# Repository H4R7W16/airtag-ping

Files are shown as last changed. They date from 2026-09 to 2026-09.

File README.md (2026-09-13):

# PING · der kleine Schlüsselwächter

**Ein AirTag-Cover für den Schlüsselbund – in FreeCAD konstruiert, mit zwei PETG-Druckteilen, zwei gesicherten Schrauben und einem Zwinkern.**

Dieses öffentliche Repository dokumentiert den Entwurf und macht die Dateien, den Erzeugungscode und die Prüfmethoden zugänglich. **Stand: digital geprüfter Konstruktionsprototyp; noch nicht physisch gedruckt oder belastungsgeprüft.**

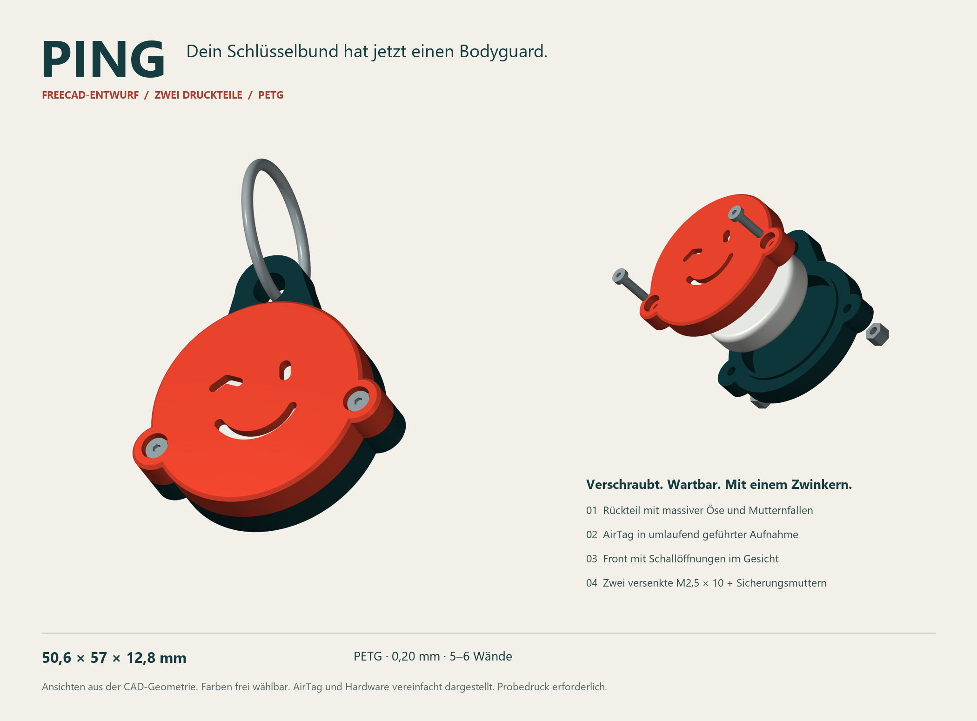
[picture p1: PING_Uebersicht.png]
PING – tatsächliche CAD-Geometrie, montiert und explodiert


## Direkt zu den Dateien

| Zweck | Datei |
|---|---|
| In FreeCAD bearbeiten | [PING_AirTag.FCStd](PING_AirTag.FCStd) |
| Rückteil drucken | [PING_Rueckteil.stl](PING_Rueckteil.stl) |
| Front drucken | [PING_Front.stl](PING_Front.stl) |
| In anderer CAD-Software öffnen | [PING_Montage.step](PING_Montage.step) |
| Druck, Teileliste und Montage | [Bebilderte Anleitung](README_Druck_und_Montage.md) |
| Erzeugung nachvollziehen | [FreeCAD-Makro](PING_erzeugen.FCMacro) · [Reproduktion](docs/REPRODUZIEREN.md) |
| Ergebnis überprüfen | [Prüfprogramm](verify_model.py) · [Prüfbericht](Pruefbericht.json) · [Prüfmethoden](docs/PRUEFUNG.md) |
| Herkunft und Entscheidungen | [Entwurfsdokumentation](docs/ENTWURF_UND_HERKUNFT.md) |

Einzeldateien über **Download raw file** herunterladen oder das gesamte Repository mit **Code → Download ZIP** beziehen. STL- und CAD-Dateien sind echte binäre Dateien, keine Git-LFS-Platzhalter.

## Konstruktion

- **50,6 × 57 × 12,8 mm** ohne Schlüsselring; Aufnahme Ø32,5 × 8,6 mm für den dokumentierten AirTag-Hüllraum Ø31,9 × 8,0 mm.
- Integrierte Öse im Rückteil: 6,4 mm dick, Ringöffnung Ø6,5 mm.
- Umlaufende Zentrierlippe; Front mit Gesicht als Schallöffnung.
- Zwei **M2,5×10-Linsenkopfschrauben** und zwei **selbstsichernde M2,5-Muttern, SW5 × 3,8 mm**. Genaue Anforderungen stehen in der [Stückliste](README_Druck_und_Montage.md#einkaufsliste).
- Für einen FDM-Drucker mit 0,4-mm-Düse und PETG ausgelegt. Startwerte: 0,20-mm-Schichten, 5–6 Wände, 40–50 % Infill. Beide STLs liegen bereits in Drucklage. Ein konkretes Drucker-/Filamentprofil wurde noch nicht erprobt.

Das Modell enthält native FreeCAD-Bodies, Skizzen, Pads, Pockets und Fasen. Die Tabelle steuert Funktionsmaße; Außenkontur, Gesicht, Schraubenpositionen und Muttern-Sechskante sind fixierte, bearbeitbare Skizzen. Es ist **kein vollständig skalierbares Universalgehäuse**.

## Was ist überprüft?

Die lokale FreeCAD-Prüfung öffnet das gespeicherte Modell erneut und kontrolliert Körpergültigkeit, Außenmaße, Kollisionen mit AirTag und Hardware sowie STEP- und STL-Exporte. Die Prüfprogramme, Toleranzen und Ergebnisse stehen offen im Repository.

Der GitHub-Workflow prüft **SHA-256-Dateiintegrität und Python-Syntax**, nicht die CAD-Geometrie. Für Letztere ist eine lokale FreeCAD-Laufzeit erforderlich. Prüfsummen sichern die Konsistenz dieses Dateistands; sie sind kein unabhängiger Sicherheitsnachweis.

**Noch offen:** Passung mit realem AirTag, Klappern, Drucktoleranzen, Signalton/Funkfunktion, Schraubensicherung sowie Zug-, Verdreh- und Falltests. Es gibt keine zugesicherte Bruchlast, keine FEM und keine Einstufung als unzerbrechlich. Hinweise dazu und eine ausfüllbare [Testvorlage](docs/PROBEDRUCK_PROTOKOLL.md) helfen bei der weiteren Erprobung.

## Kurz überprüfen

Ohne FreeCAD, mit Python 3:

```console
python verify_files.py
```

Mit der zu FreeCAD gehörenden Python-Laufzeit unter Windows, aus dem Repository-Ordner:

```powershell
& 'C:\Program Files\FreeCAD 1.1\bin\python.exe' .\verify_model.py
```

Ergebnis: `build/Pruefbericht.json`. Details, vollständige Neu-Erzeugung und bekannte Plattformgrenzen: [Reproduzieren](docs/REPRODUZIEREN.md).

## Quellen, Beiträge und Nutzungsrechte

Der Entwurf wurde im Dialog mit OpenAI Codex erstellt und mit FreeCAD 1.1.3 umgesetzt. Die Ansichten stammen aus CAD-Geometrie; AirTag und Metallteile sind vereinfacht dargestellt. Maße und Materialquellen sind in der [Anleitung](README_Druck_und_Montage.md#quellen-und-eigene-festlegungen) verlinkt. Keine Verbindung zu oder Freigabe durch Apple.

Beobachtungen können als Issue mit Drucker, Material, Profil, Commit und Fotos dokumentiert werden. Bitte geometrische Prüfung und reale Erprobung getrennt ausweisen.

Für dieses öffentliche Dokumentationsrepository wurde bislang **keine gesonderte freie Nachnutzungslizenz festgelegt**. Eine solche Lizenz wird nicht allein aus der öffentlichen Sichtbarkeit abgeleitet.

*English: PING is a FreeCAD AirTag keychain enclosure. CAD, printable STLs, STEP, generator, validation scripts and documentation are provided for inspection. Digitally checked prototype; physical testing is still pending.*

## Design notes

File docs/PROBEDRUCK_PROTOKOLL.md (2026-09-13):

# Probedruck-Protokoll

**Leere Vorlage, kein bestandener Testbericht.** Für einen tatsächlichen Test kopieren und ausfüllen.

| Feld | Eintrag |
|---|---|
| Datum / prüfende Person | |
| Repository-Commit / Dateiprüfsummen | |
| Änderungen am Entwurf | |
| Drucker / Düse / Slicer und Version | |
| Materialhersteller / Sorte / Charge / Trocknung | |
| Schichthöhe / Wände / Infill / Boden und Deckschichten | |
| Temperaturen / Kühlung / Druckausrichtung | |
| Tatsächliche Schrauben und Muttern | |
| AirTag-Generation | |

## Sicht- und Passprüfung

- [ ] Keine Risse, fehlenden Wände oder sichtbare schlechte Schichtbindung.
- [ ] Muttern sitzen vollständig; Schrauben greifen durch den Sicherungsbereich.
- [ ] Fuge schließt umlaufend ohne Verformung.
- [ ] AirTag lässt sich einlegen und wieder entnehmen; kein störendes Klappern.
- [ ] Ring lässt sich aufziehen und frei bewegen.
- [ ] Signalton, Erkennung und verfügbare Suchfunktionen geprüft.

Beobachtungen, Messwerte und Fotos:

## Mechanische Erprobung mit Dummy

Prüfaufbau, Belastungsrichtung, gemessene Kraft, Anzahl der Lastwechsel bzw. Fallhöhe und Untergrund dokumentieren. Keine pauschale Freigabe aus einem einzelnen erfolgreichen Test ableiten.

Aufbau und Belastung:

Beobachtungen, Schäden und Fotos:

## Schlussfolgerung

Was wurde tatsächlich beobachtet? Was bleibt ungetestet? Welche Änderung wird daraus abgeleitet?

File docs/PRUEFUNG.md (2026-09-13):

# Prüfmethode und Aussagegrenzen

`verify_model.py` wird mit einer FreeCAD-Python-Laufzeit ausgeführt und öffnet die FCStd-Datei erneut. Es prüft den dokumentierten **Ausgangsentwurf**, kein beliebig geändertes parametrisches Modell. Die Prüfmaße sind bewusst unabhängig vom Generator als Sollwerte hinterlegt.

| Prüfung | Kriterium |
|---|---|
| CAD-Körper | Zwei Bodies; je genau ein gültiger Solid, Volumen > 1000 mm³ |
| Vollständige Rückteilkontur | Breite 50,6 und Höhe 57,0 mm, Toleranz 0,01 mm |
| Hälften | Überschneidungsvolumen < 0,00001 mm³ |
| AirTag-Passraum | Vollständiger Hüllzylinder Ø31,9 × 8,0 mm, von Z=2,4 bis 10,4, kollisionsfrei |
| Schrauben | Zwei vereinfachte Ø2,5×10-Schäfte, Kopf Ø4,5×1,5 mm, kollisionsfrei |
| Muttern | Sechskant SW5×3,8 mm, Z=1 bis 4,8, kollisionsfrei |
| Gewindeeingriff | Nominale axiale Maßkette: 0,6 mm Überstand durch Mutter, Schraubenspitze 0,4 mm innerhalb der Rückseite |
| Beispielring | Geschlossener Torus, Außen-Ø29,2 mm, Draht-Ø2,2 mm, kollisionsfrei |
| STEP | Zwei gültige Solids; beidseitige CAD/STEP-Volumendifferenz jeweils < 0,0001 mm³ |
| STL | Geschlossenes Netz, eine Komponente, Zmin innerhalb 0,0001 mm auf dem Druckbett |
| Exporttreue STL/CAD | Symmetrische Volumendifferenz < 0,3 % und alle sechs Bounding-Box-Grenzen innerhalb 0,05 mm |
| Neuberechnung | Kein Objektstatus mit `Invalid` oder `Error` |

Die STL-Geometrie wird als Volumenkörper rekonstruiert und mit der CAD-Geometrie in Drucklage verglichen. Ein nur geschlossener, aber geometrisch falscher Export reicht damit nicht aus. Die 0,3 % berücksichtigen die Tessellierung; sie sind **keine Fertigungstoleranz**.

Hardware wird vereinfacht geprüft: keine Gewindegeometrie, keine Nylon-Verformung, kein Einschraubmoment und kein detaillierter Splitring-Montagevorgang. Der nominelle Schraubenüberstand ist eine Maßkettenprüfung, kein Test der tatsächlichen Sicherungswirkung. Ein geteilter Ring kann beim Aufziehen mehr Platz benötigen als der modellierte geschlossene Torus.

## Öffentliche Nachweise

- `Pruefbericht.json`: Test auf den veröffentlichten Produktdateien.
- `Reproduktionsbericht.json`: Test auf separaten, frisch aus dem veröffentlichten Makro erzeugten Produktdateien.
- `SHA256SUMS`: Integritätsmanifest der versionierten Projektdateien.
- GitHub-Workflow: prüft das Manifest sowie die Syntax der Python-Programme/des Makros. Er installiert kein FreeCAD und behauptet keine automatische CAD-Prüfung.

Die Berichte stammen aus der Erstellung dieses Projekts. Sie sind nachvollziehbar und erneut ausführbar, aber keine externe Zertifizierung oder unabhängige Laborprüfung.

## Offene physische Validierung

Kein realer Druck, keine Fall-/Zug-/Dauerbelastung, keine FEM, kein Test der Temperaturbeständigkeit, keine Messung des Signaltons oder der Funkfunktion. Materialdaten eines PETG-Filaments übertragen sich nicht automatisch auf den gedruckten Bauteilquerschnitt.

Die [Probedruck-Vorlage](PROBEDRUCK_PROTOKOLL.md) trennt Beobachtungen von Schlussfolgerungen. Änderungen an Material, Druckausrichtung, Schichtbindung, Passung oder Verschraubung erfordern eine erneute praktische Bewertung.

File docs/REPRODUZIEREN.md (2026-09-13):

# Dateien und Geometrie reproduzieren

## Referenzumgebung

Getestet unter Windows mit FreeCAD **1.1.3**, Build `145529fe741292ff0b3977a01195bf0247425794`, dessen eingebauter Python-3.11-Laufzeit und OpenCASCADE. Für die optionalen CAD-Renderings wurden VTK 9.3.1 und Pillow 12.0.0 verwendet. Es werden keine externen FreeCAD-Add-ons benötigt.

FreeCAD enthält C++-Python-Module. Ein beliebiges `pip install` oder der normale System-Python ersetzt diese Laufzeit nicht. Die Dokumentation beschreibt die tatsächlich getestete Windows-Konfiguration. Andere FreeCAD-Versionen und Betriebssysteme wurden nicht ausgeführt. Die Skripte unterstützen optional `FREECAD_LIB` als Modul-Suchpfad; passende Binärversionen und abhängige Bibliotheken bleiben Voraussetzung.

## 1. Dateistand prüfen

Im entpackten Repository mit Python 3:

```console
python verify_files.py
```

Das Skript prüft alle in `SHA256SUMS` gelisteten Dateien. Ein abweichender Hash beendet die Prüfung mit Fehler. Dafür ist kein FreeCAD nötig. Bei beabsichtigten Änderungen lässt sich das Manifest mit `python verify_files.py --write` neu erstellen; anschließend dokumentieren, was geändert und neu geprüft wurde.

## 2. Mitgelieferte Geometrie prüfen

PowerShell im Repository-Ordner:

```powershell
$pingPython = 'C:\Program Files\FreeCAD 1.1\bin\python.exe'
& $pingPython .\verify_model.py
```

Die Prüfung liest die versionierte FCStd-, STEP- und STL-Dateien. Sie verändert das CAD nicht. Standardmäßig schreibt sie ihren Bericht nach `build/Pruefbericht.json`. Ohne `-O` ausführen, damit Assertions aktiv bleiben. Das Skript verweigert einen optimierten Python-Lauf.

```powershell
& $pingPython .\verify_model.py --artifact-dir . --report .\build\mein-pruefbericht.json
```

## 3. Konstruktion neu erzeugen

```powershell
& $pingPython .\PING_erzeugen.FCMacro
& $pingPython .\verify_model.py --artifact-dir .\build --report .\build\neu-erzeugt-pruefung.json
```

Der Generator legt standardmäßig `build/` an und erstellt dort FCStd, STEP, STL sowie BREP-Zwischenexporte. Die versionierten Originaldateien bleiben dadurch erhalten. Wiederholungen überschreiben gleichnamige Dateien innerhalb von `build/`. Der Generator baut seine dokumentierten Ausgangswerte; Änderungen an einer FCStd-Datei werden nicht als Eingabe übernommen.

Ein anderer Zielordner kann pro Sitzung gewählt werden:

```powershell
$env:PING_OUTPUT_DIR = Join-Path (Get-Location) 'build-variante'
& $pingPython .\PING_erzeugen.FCMacro
Remove-Item Env:PING_OUTPUT_DIR
```

Alternativ das Erzeugermakro in FreeCAD über **Makro → Makros** auswählen und ausführen. Auch dort ist `build/` neben dem Makro der Standard-Ausgabeordner. Bei der Kommandozeilenausführung wird die FreeCAD-GUI für Ansichtsattribute im Offscreen-Modus initialisiert. Die Referenzumgebung meldete dabei Qt-/OpenGL-Warnungen; die maßgebliche Erfolgskontrolle sind die exportierten Dateien und die anschließende Geometrieprüfung.

## 4. Ergebnisse vergleichen

FCStd/STEP können Zeitstempel, Ansichtsmetadaten oder Serialisierungsdetails enthalten. Deshalb ist ein identischer SHA-256-Hash eines **neu erzeugten** CAD-Containers nicht garantiert. Die Prüfsummen gelten für den veröffentlichten Stand. Für die Reproduktion vergleichen wir Geometrie, Volumina, Außenmaße und gültige Exporte innerhalb der [dokumentierten Toleranzen](PRUEFUNG.md).

`Pruefbericht.json` enthält die Prüfung des veröffentlichten Dateistands. `Reproduktionsbericht.json` enthält denselben Test auf einem separaten frisch erzeugten Satz. Kleine Gleitkommaabweichungen sind möglich. Das allein beweist keine echte mechanische Robustheit.

## 5. Optionale Vorschau erzeugen

Die Referenzinstallation enthielt VTK und Pillow. Mit diesen Bibliotheken in derselben FreeCAD-Python-Laufzeit:

```powershell
& $pingPython .\render_preview.py
```

Die Bilder entstehen unter `build/previews/`. Für einen neu erzeugten Datensatz:

```powershell
& $pingPython .\render_preview.py --artifact-dir .\build --output-dir .\build\neue-ansichten
```

Schriften: standardmäßig Windows Segoe UI, alternativ DejaVu Sans; eigene TTF-Pfade über `PING_FONT_REGULAR` und `PING_FONT_BOLD`. Grafiktreiber, VTK und Schrift beeinflussen die Bildausgabe. Renderings werden nicht als pixelidentisch reproduzierbar behauptet. Die mitgelieferte `PING_FreeCAD_Ansicht.png` ist eine separat aus der echten FreeCAD-GUI gespeicherte Modellansicht; das VTK-Skript erzeugt die vier übrigen Bilder.

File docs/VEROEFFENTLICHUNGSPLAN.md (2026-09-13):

# Veröffentlichung von PING

Auftrag: Das AirTag-Cover öffentlich auf GitHub dokumentieren und die Ergebnisse für Dritte überprüfbar machen.

1. Projektdateien gezielt übernehmen: CAD, STEP, STL, Ansichten, Generator, Prüf- und Renderprogramm. Keine lokalen App-Logs, Backups oder privaten Workspace-Notizen veröffentlichen.
2. README, Reproduktionsanleitung, Prüfmethoden und Herkunft dokumentieren. Physische Erprobung ausdrücklich als offen kennzeichnen.
3. Generator in ein separates Ausgabeverzeichnis schreiben lassen. Lokale Prüfprogramme auf mitgelieferte und neu generierte Artefakte anwenden. Geometrie von CAD, STEP und STL vergleichen.
4. SHA-256-Manifest und schlanken GitHub-Integritätscheck bereitstellen. Dieser ersetzt keine FreeCAD-Geometrieprüfung.
5. Neues öffentliches Repository H4R7W16/airtag-ping anlegen, sauberen Checkout unter Repos verwenden, Dateien committen und pushen. Vor Commit/Push Remote abrufen und per Fast-forward synchronisieren.
6. Öffentliche Sichtbarkeit, Dateistand und automatischen Check prüfen. Commit und URL im lokalen Projekt-Handoff dokumentieren.

Die Veröffentlichung ist durch den Nutzerauftrag freigegeben. Keine Änderungen am Produktdesign vorgesehen; Anpassungen betreffen Reproduzierbarkeit und Dokumentation.

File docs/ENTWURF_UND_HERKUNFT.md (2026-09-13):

# Entwurf, Herkunft und Entscheidungen

## Auftrag

Ein schönes, stabiles AirTag-Cover für den Schlüsselbund, druckbar auf einem 3D-Drucker, gerne überraschend oder mit Witz. Schrauben waren erlaubt. Die Konstruktion sollte in FreeCAD entstehen. Anschließend wurde eine öffentliche Dokumentation für die Überprüfung durch Dritte beauftragt.

## Ergebnis

„PING“ ist eine verschraubte Grinse-Kapsel. Die Öse gehört zum Rückteil; eine umlaufende Lippe führt die Front. Zwei seitliche Verschraubungen liegen außerhalb des AirTag-Raums. Augen und Mund sind zugleich Schallöffnungen. Die zweiteilige Bauweise erlaubt zwei Farben ohne Mehrmaterialdruck.

Eine alleinige Schnappverbindung wurde wegen ihrer Abhängigkeit von Material und Drucktoleranz nicht gewählt. Ein umlaufendes gedrucktes Gewinde hätte mehr Bedienraum benötigt. Die verschraubte Lösung ist wartbar, dafür größer und beim Batteriewechsel werkzeugabhängig.

## Herkunft und Werkzeuge

Entwurf am 13.09.2026 im Dialog mit OpenAI Codex. Das native CAD wurde mit FreeCAD 1.1.3 über dessen Python-API konstruiert. Es handelt sich um native Skizzen-/PartDesign-Operationen, keine bloß importierte STL. Die Produktansichten wurden mit VTK/Pillow aus den realen CAD-Körpern gerendert; eine weitere Ansicht direkt in der FreeCAD-GUI.

Die Face-/AirTag-Darstellungen sind keine Hersteller-CAD-Daten. Für den AirTag wurde der von Apple veröffentlichte Hüllzylinder angenommen. PETG und die 0,4-mm-Düse sind Entwurfsannahmen; ein konkreter Drucker wurde nicht festgelegt. Quellen stehen in der Druck-/Montageanleitung.

## Während der Entwicklung behobener Fehler

Die zweidimensionale Vereinigung koplanarer FreeCAD-Flächen hinterließ zunächst mehrere Teilflächen. Die Übernahme allein der ersten Teilfläche in eine Skizze ließ Teile der Öse bzw. Schraubenohren fehlen. Der Fehler wurde durch einen Vergleich mit den erwarteten Außenmaßen erkannt. Das veröffentlichte Makro vereinigt stattdessen kurz extrudierte Körper und übernimmt ihre vollständige Bodenfläche. Zusätzliche Außenmaßprüfungen schützen vor demselben Fehler.

Die Dokumentation erwähnt diesen Befund, damit nachvollziehbar bleibt, warum eine allgemeine „Shape valid“-Prüfung allein nicht ausgereicht hätte. Die veröffentlichten Produktdateien enthalten die korrigierte Kontur.

## Änderungen für die Veröffentlichung

Keine Änderung der Produktgeometrie. Generator-Ausgaben wurden nach `build/` verlegt; Prüf-/Renderprogramme erhielten Eingabe- und Ausgabeoptionen. Lokale Installationspfade wurden durch die dokumentierte FreeCAD-Laufzeit bzw. `FREECAD_LIB` ersetzt. Zusätzlich wurden Exportvergleiche und Dateiintegrität aufgenommen. Interne App-Logs, Backups und private Workspace-Notizen gehören nicht zu diesem Repository.

## Änderungsdisziplin

Bei Varianten Generator und Sollprüfungen bewusst anpassen, neu erzeugen und prüfen. Alte Berichte nicht als Beleg für eine neue Geometrie übernehmen. Gedruckte Testteile möglichst mit Commit-ID, Material und Slicerprofil dokumentieren.

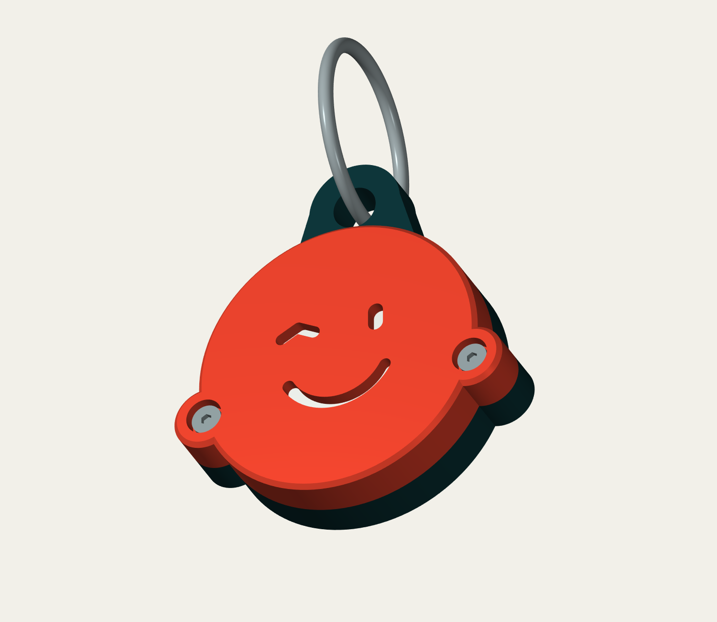
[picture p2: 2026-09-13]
PING_Vorschau.png

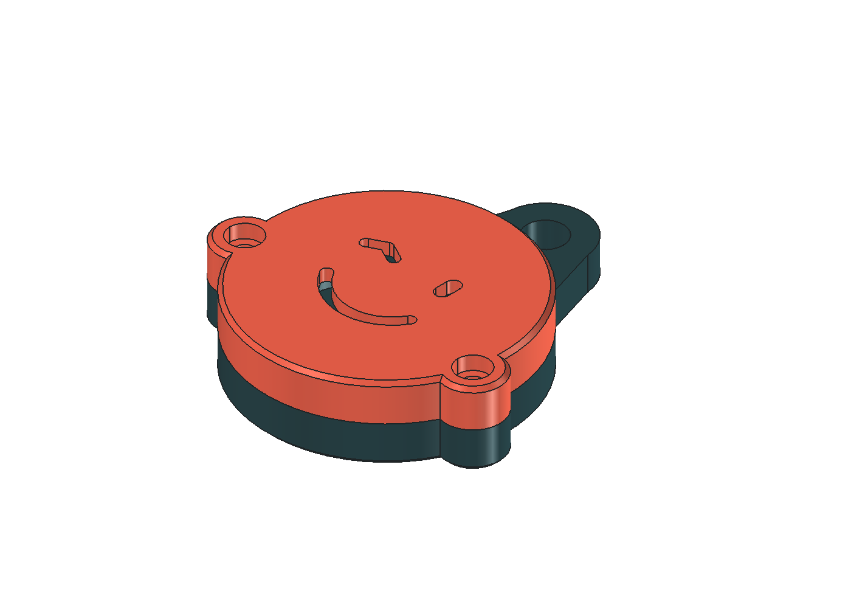
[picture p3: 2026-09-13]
PING_FreeCAD_Ansicht.png

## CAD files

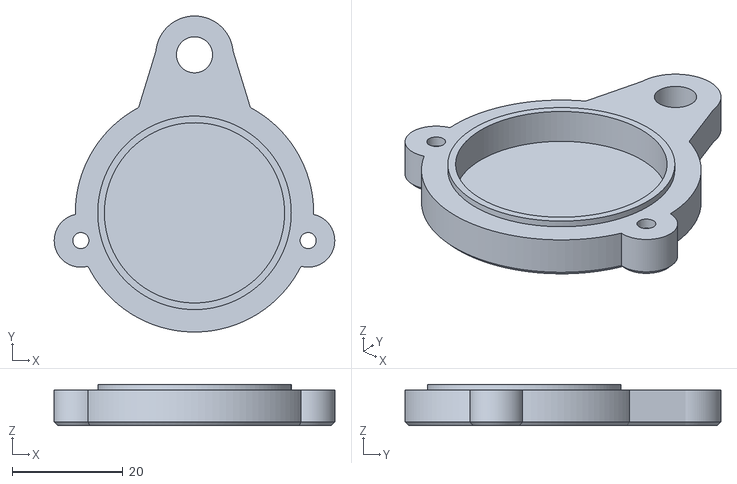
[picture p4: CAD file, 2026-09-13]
PING_Rueckteil.stl
50.6 x 57.0 x 7.40

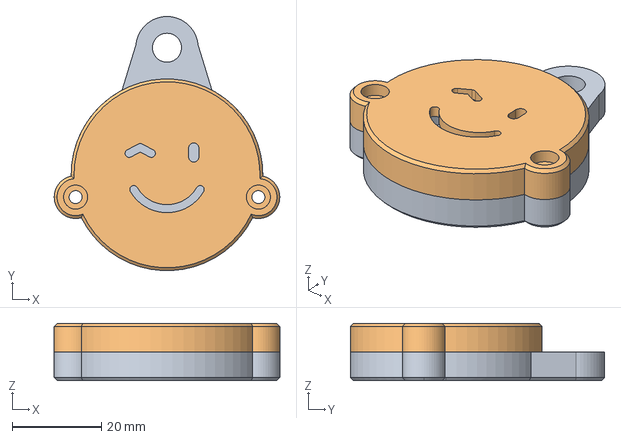
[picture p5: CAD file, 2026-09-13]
PING_AirTag.FCStd
50.6 x 57.0 x 12.8 mm
02 · Rückteil / PETG dunkel
03 · Front / PETG koralle

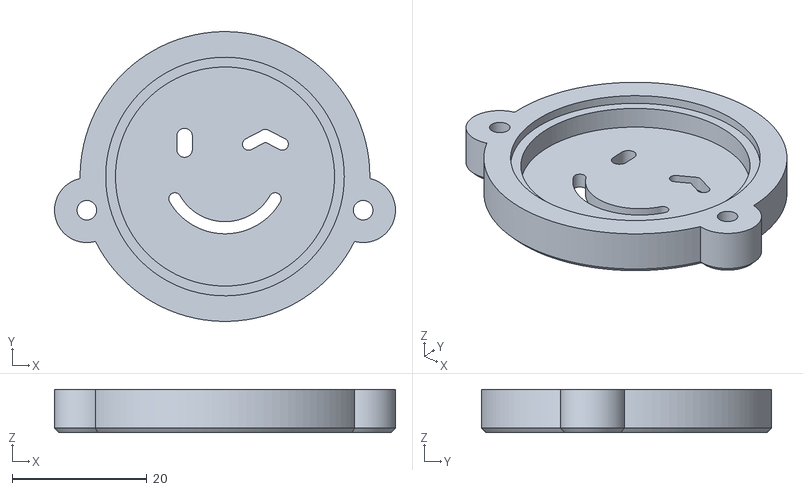
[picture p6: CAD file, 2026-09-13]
PING_Front.stl
50.6 x 43.0 x 6.40

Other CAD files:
PING_Montage.step

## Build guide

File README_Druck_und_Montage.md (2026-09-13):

# PING – der kleine Schlüsselwächter

Ein zwinkerndes AirTag-Cover mit massiver Öse, zwei versenkten Schrauben und wartbarem Gehäuse. Entworfen und geprüft mit FreeCAD 1.1.3, 13.09.2026. **Konstruktionsstand: druckbarer Prototyp, noch kein physisch erprobtes Produkt.**

PING – CAD-Ansichten

## Dateien

| Datei | Verwendung |
|---|---|
| `PING_AirTag.FCStd` | Native FreeCAD-Datei mit zwei Bodies, Skizzen, Pads, Pockets, Fasen und Parametertabelle. Hälften in Montageposition. |
| `PING_Rueckteil.stl` | Einmal drucken, bereits in Drucklage. |
| `PING_Front.stl` | Einmal drucken, bereits in Drucklage. |
| `PING_Montage.step` | Zwei getrennte Körper zum Austausch mit anderer CAD-Software; Montageposition. |
| `PING_erzeugen.FCMacro` | Reproduzierbarer Erzeuger für FreeCAD; schreibt standardmäßig in `build/`. Ein vorhandener gleichnamiger Stand in diesem Ausgabeordner wird überschrieben. |
| `Pruefbericht.json` | Ergebnisse der digitalen Geometrieprüfung. |

## Maße und Aufbau

| Merkmal | CAD-Nennmaß |
|---|---:|
| Komplettes Cover ohne Schlüsselring | 50,6 × 57,0 × 12,8 mm |
| Hauptscheibe | Ø43,0 mm |
| AirTag-Aufnahme | Ø32,5 × 8,6 mm |
| Zugrunde gelegter AirTag | Ø31,9 × 8,0 mm |
| Spiel für AirTag | 0,3 mm radial, insgesamt 0,6 mm in der Höhe |
| Frontwand und Boden | je 2,1 mm |
| Öse | 6,4 mm dick, Außenradius 7,0 mm |
| Schlüsselringöffnung | Ø6,5 mm; nominell 3,75 mm Material bis Außenrand oben |
| Umlaufende Führung | 1,0 mm hoch, 1,2 mm breit |
| Führungsspiel | 0,25 mm radial und axial |
| Schraubendurchgänge | Ø2,9 mm |
| Kopftaschen | Ø5,4 × 2,4 mm tief |
| Mutternfallen | SW5,35 × 4,8 mm tief |

Die Schlüsselringlast geht direkt in das Rückteil. Die Front verschließt den AirTag mit zwei Schrauben. Die umlaufende Lippe führt die Hälften und unterstützt sie gegen seitliche Verschiebung. Augen und Mund sind durchgehende Schallöffnungen. Die Front deckt den AirTag weitgehend ab, bietet durch diese Öffnungen aber keinen vollständigen Kratz- oder zusätzlichen Wasserschutz.

## Material und Druck

**Voreinstellung: FDM, PETG, Düse 0,4 mm.** Drucker und Material wurden nicht näher genannt. Petrol/Anthrazit hinten und Koralle/Orange vorne funktionieren ohne Mehrfarbdruck: jedes Teil erhält eine Filamentfarbe.

- Beide STL-Dateien in **Millimetern und mit 100 % Skalierung** importieren. Sie liegen mit der flachen Außenseite auf Z=0; die offenen Innenseiten zeigen nach oben.
- Schichthöhe 0,20 mm; 5–6 Wandlinien; mindestens 6 Boden-/Deckschichten; 40–50 % Gyroid als Startwert. Öse und Schraubenohren im Slicer bei Bedarf mit einem 100-%-Infill-Modifikator versehen. Mit dieser Wandzahl werden die schmalen Bereiche ohnehin weitgehend massiv.
- Normalerweise ohne Stützmaterial druckbar. In der Schichtvorschau besonders die kurzen Brücken über Kopf- und Mutternfallen prüfen. Falls das PETG-Profil dort unsauber brückt, lokal Stützen setzen oder das Brückenprofil anpassen.
- Materialtemperaturen und Kühlung nach dem bewährten Profil für das konkrete Filament wählen. Trockene PETG-Rolle verwenden. Kein ungeprüfter Universal-Temperaturwert.
- Die Außenfase reduziert scharfe Druckbettkanten. Einen verbliebenen Elefantenfuß an Bohrungen und Passflächen vorsichtig entgraten. Die funktionale Zentrierlippe nicht abschleifen, solange sie bereits leichtgängig passt.
- PLA eignet sich für einen ersten Formtest. Für die vorgesehene Nutzung ist zähes PETG die Ausgangsempfehlung. [Prusa: PETG](https://help.prusa3d.com/article/petg_2059)

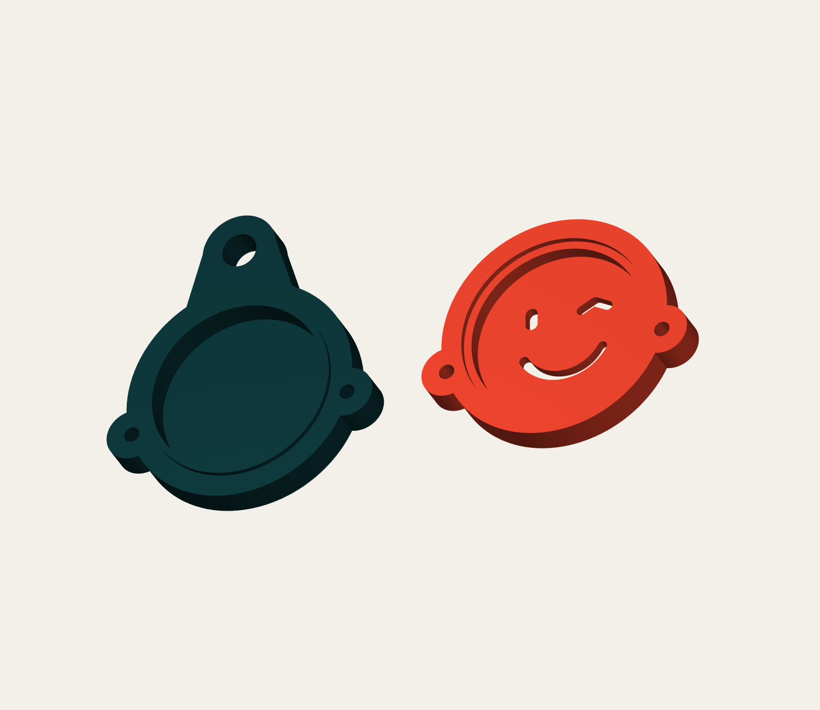
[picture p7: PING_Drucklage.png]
Beide Teile in Drucklage, von der offenen Innenseite gesehen


## Einkaufsliste

| Anzahl | Teil | Maßanforderung |
|---:|---|---|
| 2 | M2,5 × 10 mm Linsenkopf-Innensechskantschraube, z. B. ISO 7380-1 | Länge **unter dem Kopf** 10 mm, Kopf Ø maximal 4,5 mm, Kopfhöhe maximal 1,5 mm; Vollgewinde. Keine Senkkopfschraube. |
| 2 | Selbstsichernde M2,5-Sechskantmutter mit Nylonring | SW5,0 mm, Gesamthöhe 3,8 mm. Tatsächliches Lieferteil nachmessen; abweichende Bauformen sind möglich. |
| 1 | Geschlossener geteilter Schlüsselring aus Stahl | Etwa 28–30 mm außen, Draht etwa 2,0–2,2 mm. Virtuell geprüft: Ø29,2 mm außen / Draht Ø2,2 mm, als vereinfachter geschlossener Ring. |
| optional | Sehr dünne weiche Schaum-/Filzauflage | Nur falls der reale AirTag klappert; zunächst 0,3 mm dick und etwa Ø8–10 mm, zentral auf dem hinteren Boden. |

Keine Gewindeeinsätze, kein Klebstoff und keine gedruckten Gewinde nötig. Die selbstsichernden Muttern erschweren ein selbstständiges Losdrehen. Die Rückhaltung ist trotzdem regelmäßig am realen Schlüsselbund zu kontrollieren.

## Montage

1. Beide Teile entgraten. Zuerst ohne AirTag trocken zusammenstecken: Die Lippe muss in die Front gleiten und die umlaufende Trennfuge muss vollständig schließen.
2. Die beiden Muttern von der **Außenseite des Rückteils** in die Sechskanttaschen drücken. Metallische Auflagefläche tief in die Tasche, Nylonring nach außen. Die Muttern liegen anschließend ungefähr 1 mm unter der Rückseite. Beim ersten Einschrauben mit einem passenden Werkzeug gegenhalten, wenn sie noch lose sitzen.
3. Den AirTag ins Rückteil legen. Die verwendete digitale Prüfung basiert bewusst auf dem vollständigen Ø31,9 × 8,0-mm-Hüllzylinder; die genaue gewölbte Herstellerkontur wurde nicht nachmodelliert. Bei fühlbarem Spiel eine dünne zentrale weiche Auflage ergänzen. Nicht so viel unterlegen, dass die Fuge beim Schließen offen bleibt.
4. Die Front aufsetzen. Zwei M2,5×10-Schrauben von vorne einsetzen und abwechselnd vorsichtig von Hand anziehen. Die Flächen sollen satt anliegen, ohne sichtbare Verformung. Die Sicherungsmutter erzeugt schon vor dem Anschlag Widerstand; deshalb nicht allein nach dem Drehgefühl beurteilen.
5. Prüfen: Schraubenenden bleiben nominal 0,4 mm innerhalb des Rückteils und reichen 0,6 mm durch die vollständig eingesetzte 3,8-mm-Mutter. Beide Schrauben müssen durch den Nylonbereich greifen. Bei abweichender Mutterhöhe die Länge neu prüfen.
6. Schlüsselring durch die Öse ziehen. Anschließend den AirTag-Signalton, Erkennung und gegebenenfalls Präzisionssuche mit dem eigenen Gerät testen.

Zum Batteriewechsel beide Schrauben lösen und die Front abheben. Der Schlüsselring kann am Rückteil bleiben. Bei häufigem Öffnen Muttern mit nachlassender Sicherungswirkung ersetzen.

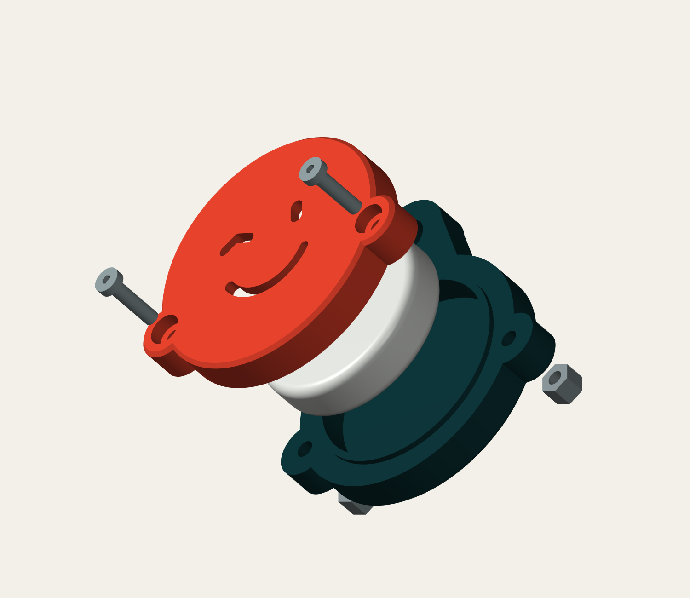
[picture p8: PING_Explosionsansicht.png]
Explosionsansicht


## In FreeCAD weiterbearbeiten

`PING_AirTag.FCStd` öffnen. Die Tabelle **01 · Maße und Druckspiel (mm)** steuert die verknüpften Durchmesser und Tiefen. Für kleine Drucktoleranzkorrekturen beispielsweise den Aufnahmedurchmesser von 32,5 auf 32,7 mm ändern und neu berechnen.

Die Außenkonturen, Schraubenpositionen, das Gesicht und die SW5,35-Sechskantkonturen sind fixierte native Skizzengeometrie. Sie bleiben bearbeitbar, sind aber **nicht vollständig durch die Tabelle gesteuert**. Insbesondere `NutAF` dokumentiert das Nennmaß; die Muttern-SW muss in `BNutSketch` bzw. im Erzeugermakro geändert werden. Für eine andere AirTag-Größe oder wesentlich andere Schrauben müssen die Konturen mit angepasst werden. Das Referenzobjekt „AirTag Hüllzylinder“ ist eine feste Prüfhilfe.

Bei geänderten Wand-/Schalenhöhen erneut Schraubenlänge und Eingriff prüfen. Das Modell ist in Montageposition gespeichert; **die mitgelieferten STL-Dateien sind bereits korrekt für den Druck gedreht**. Nach Änderungen neue STL-Dateien exportieren und die Front so drehen, dass die plane Außenseite unten liegt. Das Erzeugermakro schreibt seine Ausgangsparameter; es übernimmt keine nachträglich im FCStd geänderten Werte.

## Geprüft und noch offen

Digital bestanden: gültige Einzelvolumenkörper, vollständige Außenkonturen, kollisionsfreie Hälften, freier AirTag-Hüllzylinder, passende Schrauben und Muttern, Beispielring kollisionsfrei, STEP mit zwei Körpern, zwei geschlossene STL-Netze mit je einer Komponente und Druckbett-Z=0. Die Vorschau wurde aus diesen CAD-Körpern gerendert, nicht als Fantasiebild erzeugt.

**Noch erforderlich:** realer Probedruck, Passprobe, Klapperprüfung, Signalton-/Funktionstest sowie Zug-, Verdreh- und Fallprüfung für eure Druckeinstellungen. Nicht auf „unzerbrechlich“ oder eine bestimmte Bruchlast getestet; keine FEM und keine Freigabe für sicherheitsrelevante Befestigung. Zum ersten Belastungstest einen Dummy verwenden. Bei Weißbruch, Rissen, ausgeschlagener Öse oder lockerer Verschraubung nicht weiter am Schlüsselbund verwenden.

## Quellen und eigene Festlegungen

- AirTag-Außenmaße 2021: [Apple Support](https://support.apple.com/en-euro/111847).
- AirTag-Außenmaße 2026: [Apple Support](https://support.apple.com/en-gb/126203). Beide Quellen geben Ø31,9 × 8,0 mm an. Die digitale Passprüfung deckt diesen Hüllraum ab; eine reale Passprobe mit beiden Generationen wurde nicht durchgeführt.
- M2,5-Mutternmaß SW5 / H3,8: [Westfield Fasteners – Maßblatt](https://www.westfieldfasteners.co.uk/Datasheets/Nut_HexNy_M.pdf).
- PETG-Materialcharakteristik: [Prusa Knowledge Base](https://help.prusa3d.com/article/petg_2059).
- Gehäusegeometrie, Spiel, Verschraubungsanordnung und Druck-Startwerte sind eigene konstruktive Festlegungen.
